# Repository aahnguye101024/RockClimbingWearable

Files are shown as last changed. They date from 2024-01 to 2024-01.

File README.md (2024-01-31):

# RockClimbingWearable

The rock climbing wearable should serve as a portable device worn around one's waist when they rock climb. Operating with a lipo battery, this device uses an active GPS device, an OLED screen, and a TEENSY-LC to track your vertical distance climbed for your own training purposes.

## Board Pictures

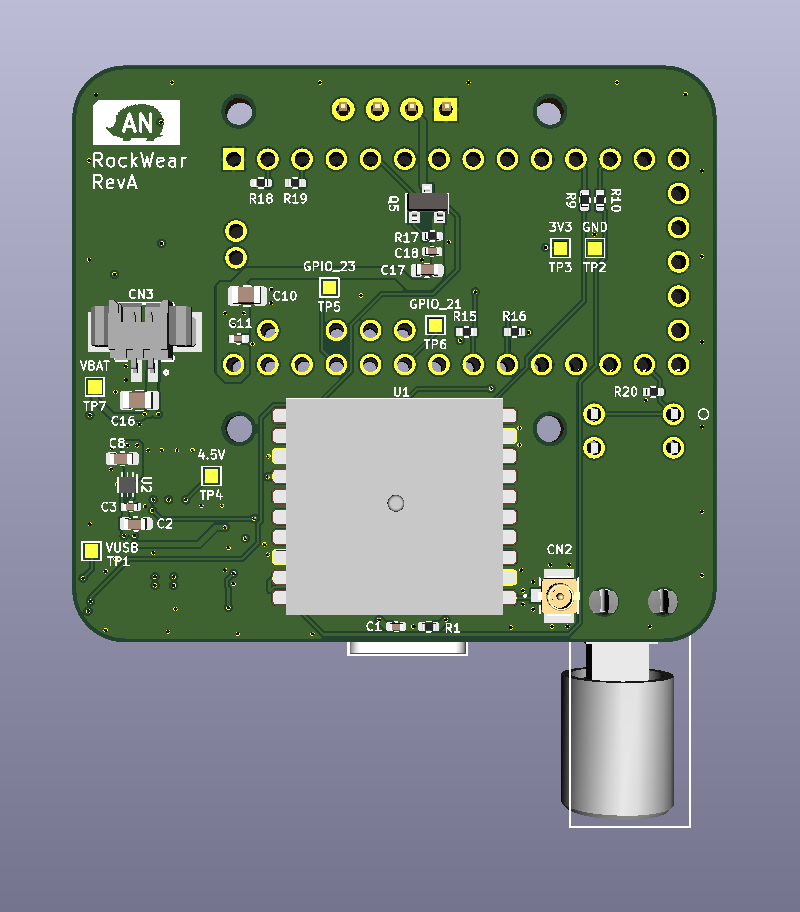
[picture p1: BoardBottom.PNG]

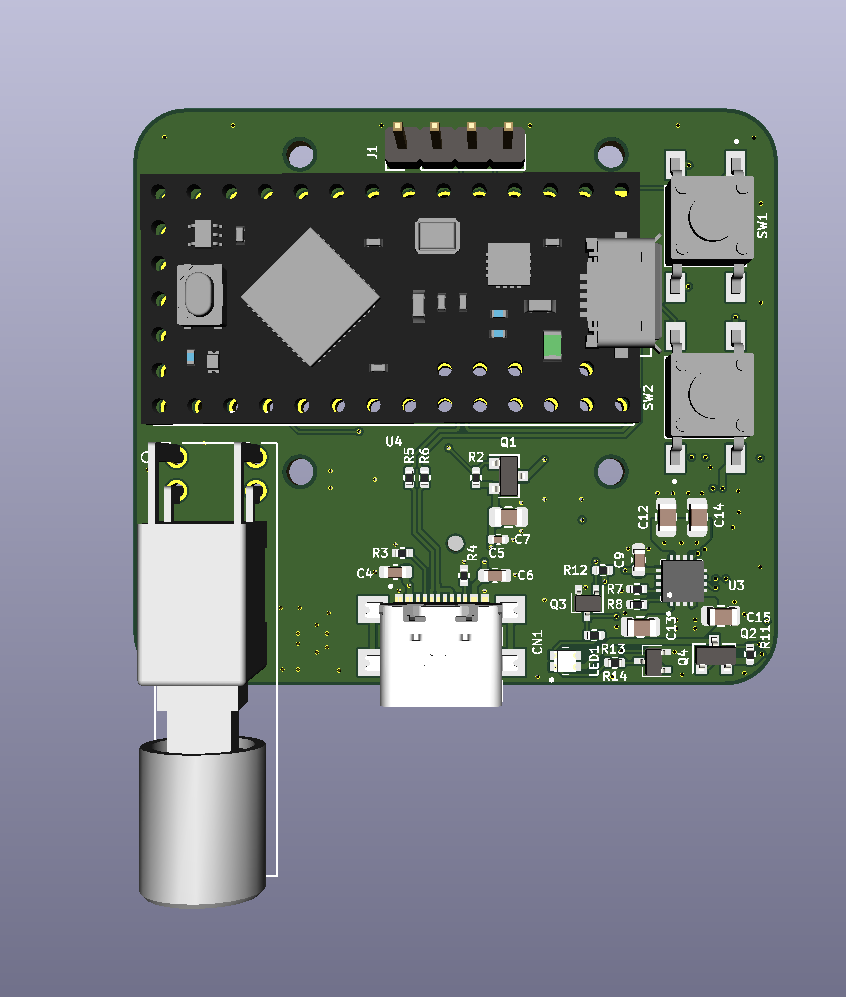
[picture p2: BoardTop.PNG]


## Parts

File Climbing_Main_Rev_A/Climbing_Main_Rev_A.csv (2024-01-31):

Source: | C:\Users\AaronN\Desktop\Personal\PersonalProjects\WearabkeRockClimbingTool\Climbing_Main_Rev_A\Climbing_Main_Rev_A.sch
Date: | 12/7/2021 23:54
Tool: | Eeschema (5.1.10)-1
Generator: | C:\Program Files\KiCad\bin\scripting\plugins/AaronsFavoriteBOMScript.py
Component Count: | 54
Ref | Qnty | Value | Cmp name | Description | Manufacturer | Part Number
C1, C3, C5, C11, C18, | 5 | 0.1uF | 0.1uF | CAP CER 0.1UF 25V X5R 0402 | Samsung Electro-Mechanics | 1276-1043-1-ND
C2, C4, C6, C8, C9, C17, | 6 | 2.2uF | 2.2uF | CAP CER 2.2UF 10V X5R 0603 | Samsung Electro-Mechanics | 1276-1085-1-ND
C7, C10, C12, C13, C14, C15, C16, | 7 | 10uF | 10uF | CAP CER 10UF 16V X5R 0805 | Samsung Electro-Mechanics | 1276-2893-1-ND
CN1, | 1 | USB4110-GF-A_REVB | USB4110-GF-A_REVB | SMD USB 2.0-only Type-C Receptacle connector | GCT | 2073-USB4110-GF-A-1-ND
CN2, | 1 | U.FL-R-SMT(10) | U.FL-R-SMT(10) | CONN U.FL RCPT STR 50 OHM SMD | Hirose Electric Co Ltd | H9161CT-ND
CN3, | 1 | 532610271 | 532610271 | PICOBLADE CONN HEADER SMD R/A 2POS 1.25MM | Molex | WM7620CT-ND
LED1, | 1 | LTST-C19HE1WT | LTST-C19HE1WT | LED RGB DIFFUSED CHIP SMD | Lite-On Inc. | 160-2162-1-ND
Q1, Q2, Q5, | 3 | NX3008PBK,215 | NX3008PBK,215 | MOSFET P-CH 30V 230MA TO236AB | Nexperia USA Inc. | 1727-1281-1-ND
Q3, Q4, | 2 | BSS138BKW,115 | BSS138BKW,115 | MOSFET N-CH 60V 320MA SOT323 | Nexperia USA Inc. | 1727-1262-1-ND
R1, | 1 | 330 | 330 | RES 330 OHM 1% 1/16W 0402 | YAGEO | 311-330LRCT-ND
R2, R11, R12, R15, R16, R17, R18, R19, R20, | 9 | 4.7k | 4.7k | RES 4.7K OHM 1% 1/16W 0402 | Stackpole Electronics Inc | RMCF0402FT4K70CT-ND
R3, R4, | 2 | 5.1k | 5.1k | RES 5.1K OHM 1% 1/16W 0402 | YAGEO | 311-5.10KLRCT-ND
R5, R6, R9, R10, | 4 | 0 | 0 | RES 0 OHM JUMPER 1/16W 0402 | Stackpole Electronics Inc | RMCF0402ZT0R00CT-ND
R7, | 1 | 1.8k | 1.8k | RES 1.8K OHM 1% 1/16W 0402 | Stackpole Electronics Inc | RMCF0402FT1K80CT-ND
R8, | 1 | 10k | 10k | RES 10K OHM 1% 1/16W 0402 | Stackpole Electronics Inc | RMCF0402FT10K0CT-ND
R13, | 1 | 390 | 390 | RES 390 OHM 1% 1/16W 0402 | Stackpole Electronics Inc | RMCF0402FT390RCT-ND
R14, | 1 | 1k | 1k | RES 1K OHM 1% 1/16W 0402 | Stackpole Electronics Inc | RMCF0402FT1K00CT-ND
SW1, SW2, | 2 | FSM2JSMAA | FSM2JSMAA | SMD Momentary PushButton | FSM2JSMAA | 450-3355-ND
SW3, | 1 | PB400EEQR1BLK | PB400EEQR1BLK | Pushbutton Switch DPST Standard Through Hole, Right Angle | E-Switch | EG5547-ND
U1, | 1 | CD-PA1616S | CD-PA1616S | Adafruit Ultimate GPS Module | Adafruit Industries LLC | 1528-5186-ND
U2, | 1 | MIC5528-3.3YMX-TR | MIC5528-3.3YMX-TR | IC REG LINEAR 3.3V 500MA 6XTDFN | Microchip Technology | 576-4452-1-ND
U3, | 1 | BQ24232HARGTR | BQ24232HARGTR | IC BATT CHG LI-ION 1CELL 16QFN | Texas Instruments | 296-49554-1-ND
U4, | 1 | Teensy-LC | Teensy-LC |  | SparkFun Electronics | 1568-1233-ND

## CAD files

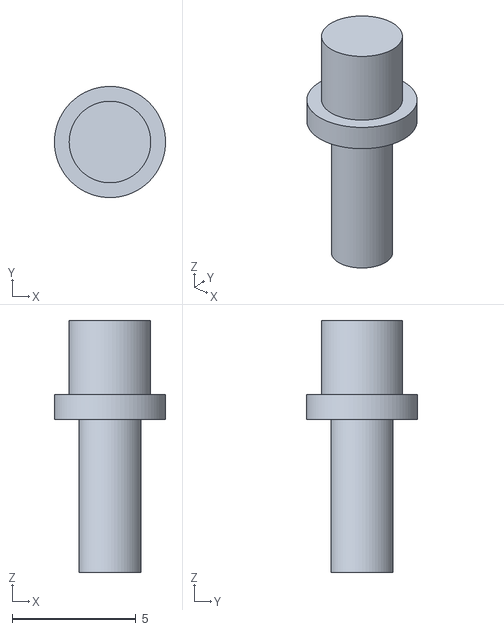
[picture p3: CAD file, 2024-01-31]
3D/Button v6.stl
4.50 x 4.50 x 10.2

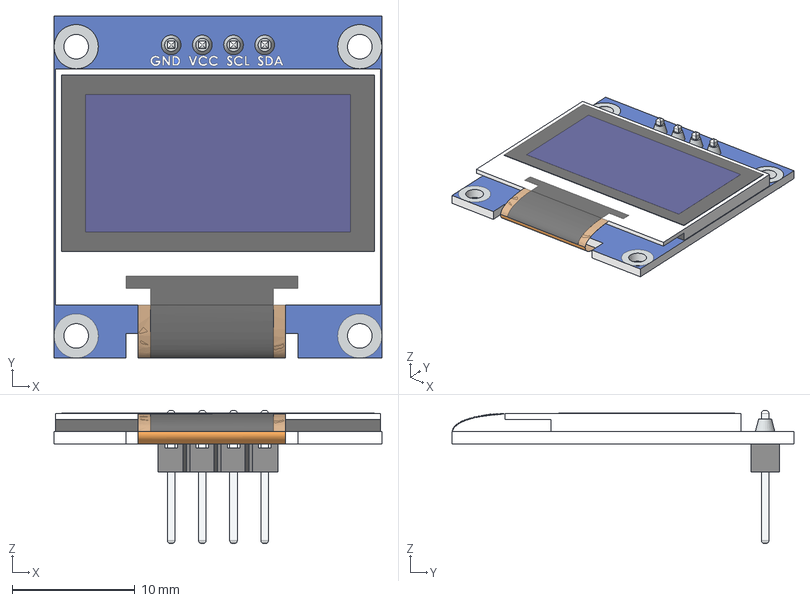
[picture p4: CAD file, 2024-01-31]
Climbing_Main_Rev_A/Step/OLED-128x64-0.96.step
26.7 x 27.9 x 10.8 mm

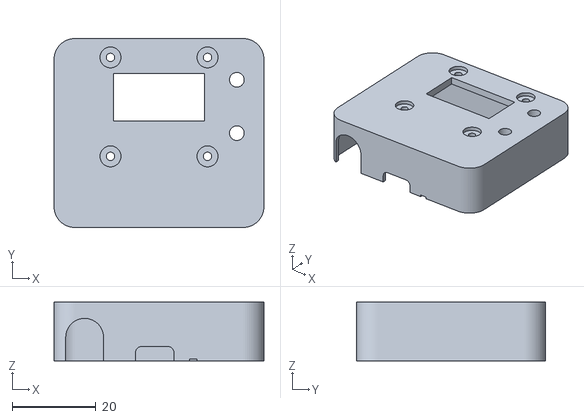
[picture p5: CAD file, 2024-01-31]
Climbing_Main_Rev_A/TopCase v10.stl
50.0 x 45.0 x 14.0

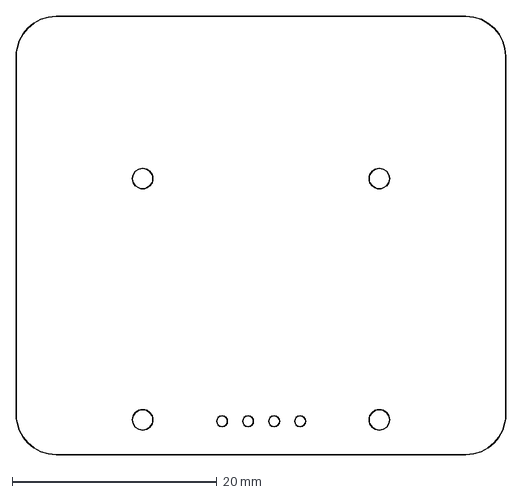
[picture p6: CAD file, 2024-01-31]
Outline.dxf
47.8 x 42.8 mm

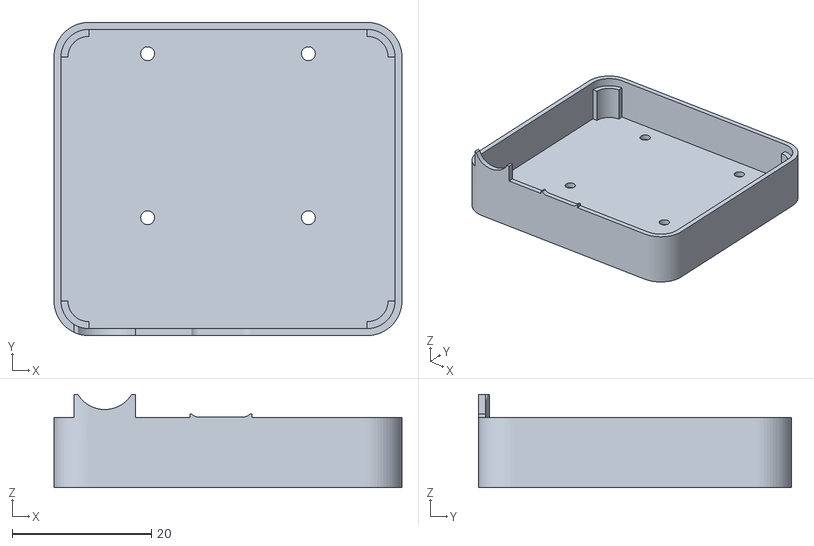
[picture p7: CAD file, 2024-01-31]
3D/BottomCase v15.stl
50.0 x 45.0 x 13.4

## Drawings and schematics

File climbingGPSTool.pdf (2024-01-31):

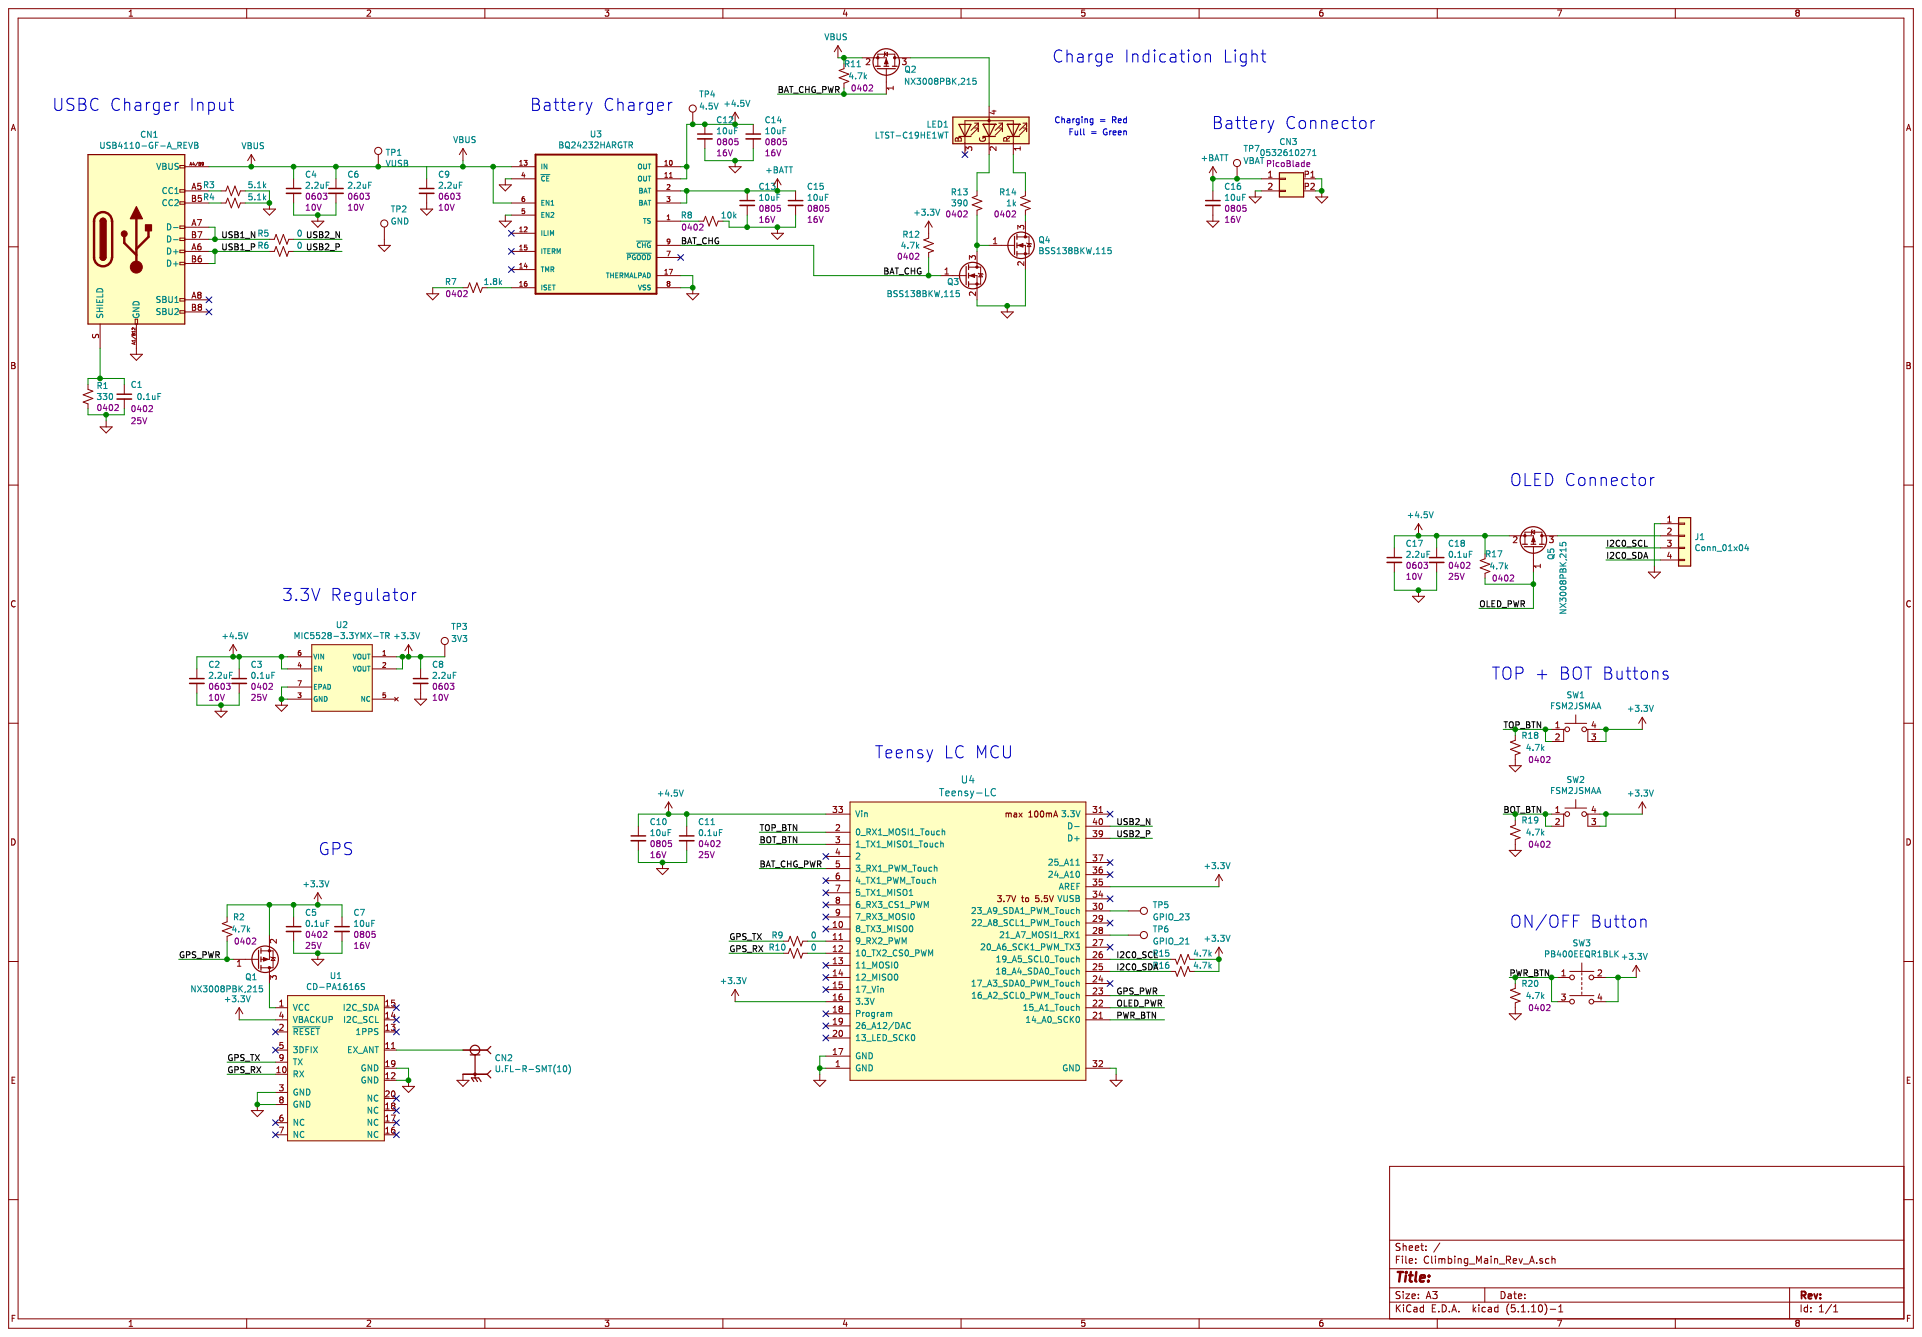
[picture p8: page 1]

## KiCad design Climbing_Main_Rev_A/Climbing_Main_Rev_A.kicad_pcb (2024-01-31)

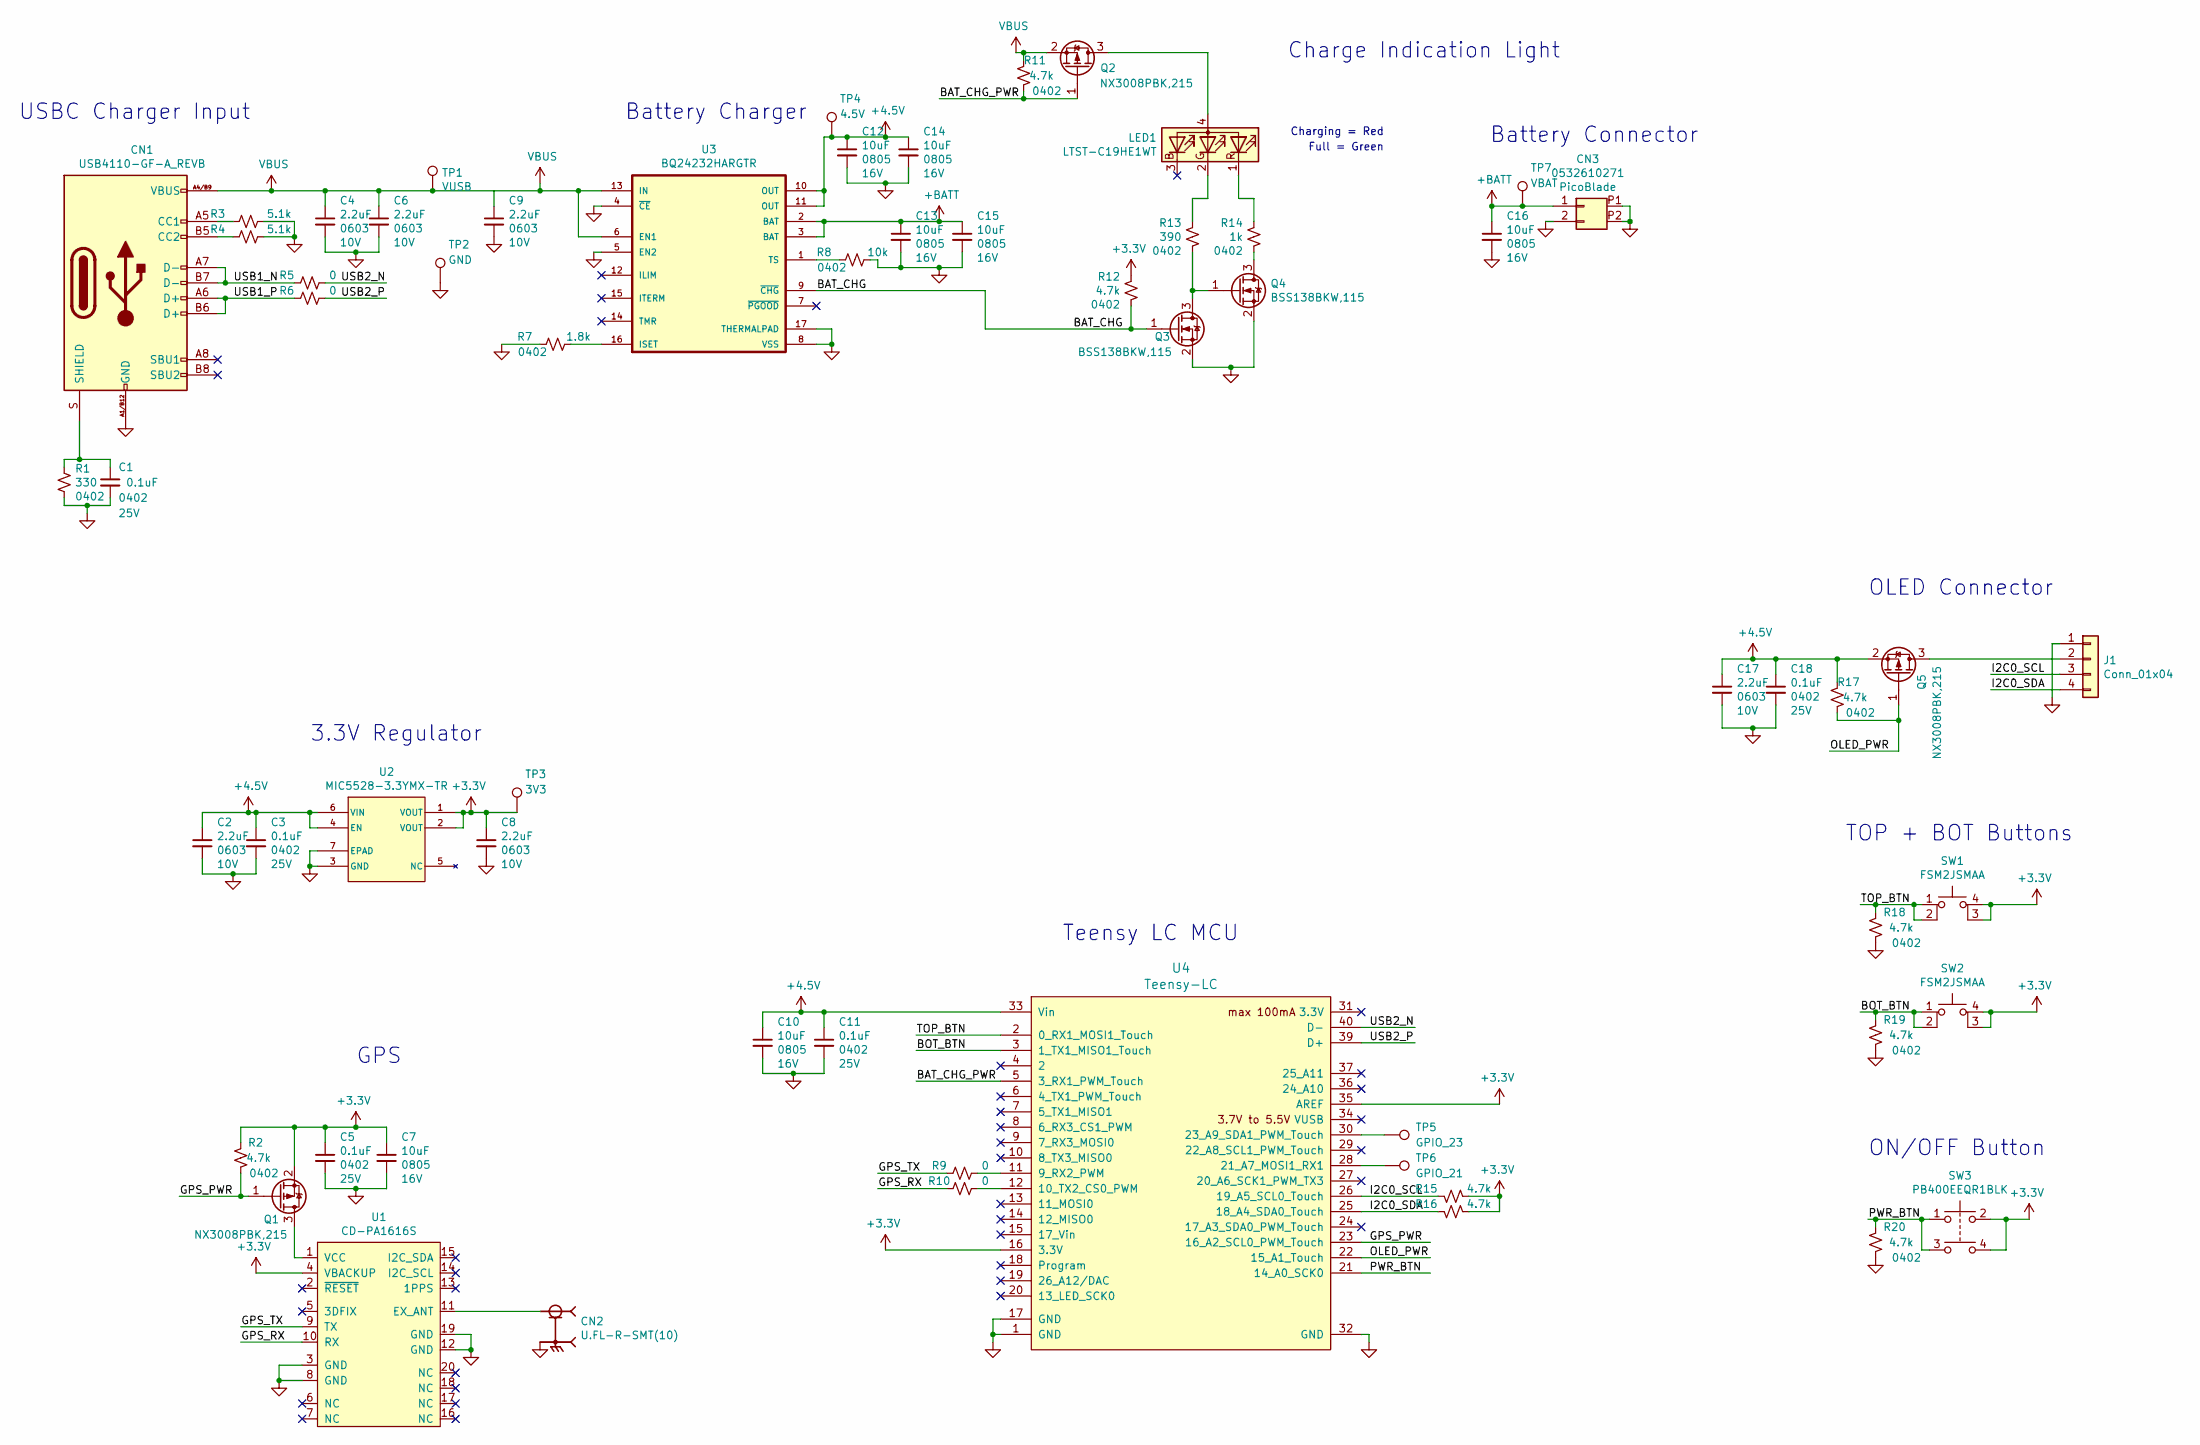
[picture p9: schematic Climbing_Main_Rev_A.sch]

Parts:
C1, C3, C5, C11, C18: 0.1uF; C_0402_1005Metric; Voltage 25V; Part Number 1276-1043-1-ND
C2, C4, C6, C8, C9, C17: 2.2uF; C_0603_1608Metric; Voltage 10V; Part Number 1276-1085-1-ND
C7, C10, C12, C13, C14, C15, C16: 10uF; C_0805_2012Metric; Voltage 16V; Part Number 1276-2893-1-ND
CN1: USB4110-GF-A_REVB; GCT_USB4110-GF-A_REVB; Part Number 2073-USB4110-GF-A-1-ND
CN2: U.FL-R-SMT(10); HRS_U.FL-R-SMT(10); Part Number H9161CT-ND
CN3: 0532610271; MOLEX_53261-0271; Part Number WM7620CT-ND
J1: Conn_01x04; PinHeader_1x04_P2.54mm_Vertical
LED1: LTST-C19HE1WT; LED_LTST-C19HE1WT; Part Number 160-2162-1-ND
Q1, Q2, Q5: NX3008PBK,215; SOT-23; Part Number 1727-1281-1-ND
Q3, Q4: BSS138BKW,115; SOT-323_SC-70; Part Number 1727-1262-1-ND
R1: 330; R_0402_1005Metric; Part Number 311-330LRCT-ND
R2, R11, R12, R15, R16, R17, R18, R19, R20: 4.7k; R_0402_1005Metric; Part Number RMCF0402FT4K70CT-ND
R3, R4: 5.1k; R_0402_1005Metric; Part Number 311-5.10KLRCT-ND
R5, R6, R9, R10: 0; R_0402_1005Metric; Part Number RMCF0402ZT0R00CT-ND
R7: 1.8k; R_0402_1005Metric; Part Number RMCF0402FT1K80CT-ND
R8: 10k; R_0402_1005Metric; Part Number RMCF0402FT10K0CT-ND
R13: 390; R_0402_1005Metric; Part Number RMCF0402FT390RCT-ND
R14: 1k; R_0402_1005Metric; Part Number RMCF0402FT1K00CT-ND
SW1, SW2: FSM2JSMAA; SW_2-1437565-8; Part Number 450-3355-ND
SW3: PB400EEQR1BLK; Part Number EG5547-ND
TP1: VUSB; CurrentTestPoint
TP2: GND; CurrentTestPoint
TP3: 3V3; CurrentTestPoint
TP4: 4.5V; CurrentTestPoint
TP5: GPIO_23; CurrentTestPoint
TP6: GPIO_21; CurrentTestPoint
TP7: VBAT; CurrentTestPoint
U1: CD-PA1616S; PA1616S; Part Number 1528-5186-ND
U2: MIC5528-3.3YMX-TR; Part Number 576-4452-1-ND
U3: BQ24232HARGTR; QFN50P300X300X100-17N; Part Number 296-49554-1-ND
U4: Teensy-LC; Teensy_LC; Part Number 1568-1233-ND

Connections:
+3V3: C5.1, C7.1, C8.1, Q1.2 (S), R2.1, R12.1, R15.2, R16.2, SW1.3 (K), SW1.4 (A), SW2.3 (K), SW2.4 (A), SW3.2, SW3.4, TP3.1, U1.4 (VBACKUP), U2.1 (VOUT), U2.2 (VOUT), U4.16 (3.3V), U4.35 (AREF)
+4V2: C2.1, C3.1, C10.1, C11.1, C12.1, C14.1, C17.1, C18.1, Q5.2 (S), R17.1, TP4.1, U2.4 (EN), U2.6 (VIN), U3.10 (OUT), U3.11 (OUT), U4.33 (Vin)
+BATT: C13.1, C15.1, C16.1, CN3.1, TP7.1, U3.2 (BAT), U3.3 (BAT)
/BAT_CHG: Q3.1 (G), R12.2, U3.9 (~CHG)
/BAT_CHG_PWR: Q2.1 (G), R11.2, U4.5 (3_RX1_PWM_Touch)
/BOT_BTN: R19.1, SW2.1, SW2.2, U4.3 (1_TX1_MISO1_Touch)
/GPS_PWR: Q1.1 (G), R2.2, U4.23 (16_A2_SCL0_PWM_Touch)
/GPS_RX: R10.2, U1.10 (RX)
/GPS_TX: R9.2, U1.9 (TX)
/I2C0_SCL: J1.3, R15.1, U4.26 (19_A5_SCL0_Touch)
/I2C0_SDA: J1.4, R16.1, U4.25 (18_A4_SDA0_Touch)
/OLED_PWR: Q5.1 (G), R17.2, U4.22 (15_A1_Touch)
/PWR_BTN: R20.1, SW3.1, SW3.3, U4.21 (14_A0_SCK0)
/TOP_BTN: R18.1, SW1.1, SW1.2, U4.2 (0_RX1_MOSI1_Touch)
/USB1_N: CN1.A7 (D-), CN1.B7 (D-), R5.2
/USB1_P: CN1.A6 (D+), CN1.B6 (D+), R6.2
/USB2_N: R5.1, U4.40 (D-)
/USB2_P: R6.1, U4.39 (D+)
GND: C1.2, C2.2, C3.2, C4.2, C5.2, C6.2, C7.2, C8.2, C9.2, C10.2, C11.2, C12.2, C13.2, C14.2, C15.2, C16.2, C17.2, C18.2, CN1.A1/B12 (GND), CN1.B1/A12 (GND), CN2.2, CN2.3, CN3.2, CN3.P1 (TAB), CN3.P2 (TAB), J1.1, Q3.2 (S), Q4.2 (S), R1.2, R3.1, R4.1, R7.2, R8.1, R18.2, R19.2, R20.2, TP2.1, U1.3 (GND), U1.8 (GND), U1.12 (GND), U1.19 (GND), U2.3 (GND), U2.7 (EPAD), U3.4 (~CE), U3.5 (EN2), U3.8 (VSS), U3.17 (THERMALPAD), U4.1 (GND), U4.17 (GND), U4.32 (GND)
unnamed: C1.1, CN1.S (SHIELD), R1.1
unnamed: CN1.A5 (CC1), R3.2
unnamed: CN1.B5 (CC2), R4.2
unnamed: CN2.1, U1.11 (EX_ANT)
unnamed: J1.2, Q5.3 (D)
unnamed: LED1.1 (RK), R14.1
unnamed: LED1.2 (GK), R13.1
unnamed: LED1.4 (A), Q2.3 (D)
unnamed: Q1.3 (D), U1.1 (VCC)
unnamed: Q3.3 (D), Q4.1 (G), R13.2
unnamed: Q4.3 (D), R14.2
unnamed: R7.1, U3.16 (ISET)
unnamed: R8.2, U3.1 (TS)
unnamed: R9.1, U4.11 (9_RX2_PWM)
unnamed: R10.1, U4.12 (10_TX2_CS0_PWM)
unnamed: TP5.1, U4.30 (23_A9_SDA1_PWM_Touch)
unnamed: TP6.1, U4.28 (21_A7_MOSI1_RX1)
VBUS: C4.1, C6.1, C9.1, CN1.A4/B9 (VBUS), CN1.B4/A9 (VBUS), Q2.2 (S), R11.1, TP1.1, U3.6 (EN1), U3.13 (IN)

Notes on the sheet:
Battery Charger
USBC Charger Input
Charge Indication Light
Full = Green
Charging = Red
3.3V Regulator
Battery Connector
GPS
Teensy LC MCU
OLED Connector
TOP + BOT Buttons
ON/OFF Button

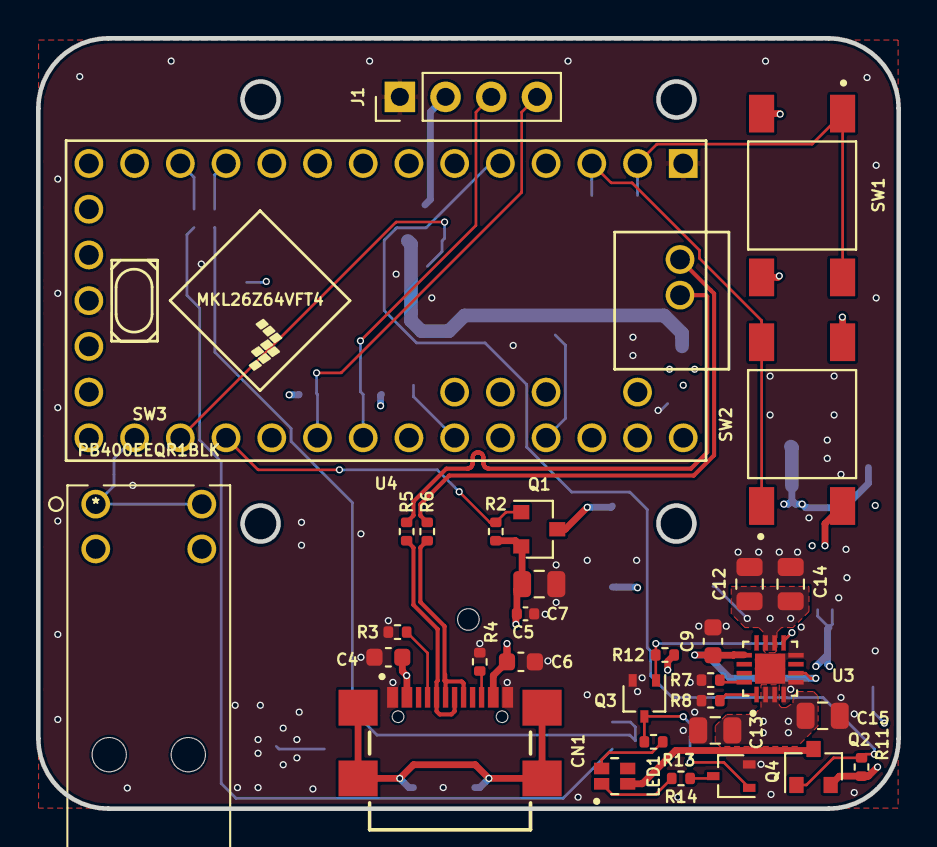
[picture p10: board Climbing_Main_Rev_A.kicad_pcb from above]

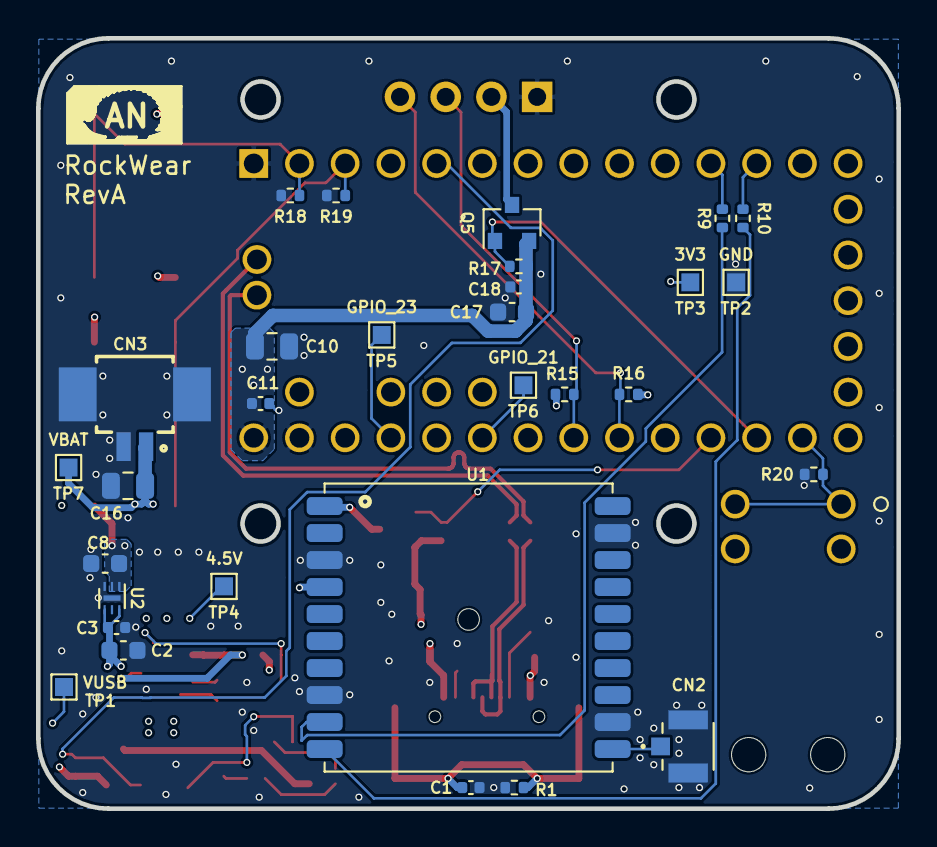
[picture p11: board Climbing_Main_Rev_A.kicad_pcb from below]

Board: 4 copper layers, 47.8 x 42.8 mm, 62 parts (30 on the bottom side), 37 nets.

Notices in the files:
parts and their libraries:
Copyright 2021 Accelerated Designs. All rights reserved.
